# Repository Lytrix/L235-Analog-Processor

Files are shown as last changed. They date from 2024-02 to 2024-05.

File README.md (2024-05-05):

# L-235 Analog Processor ##

### Introduction ###
I was interested in the [SR-235](https://www.thinksrs.com/images/instr/boxcar/SR235_FPlg.jpg) as being the equivalent mathematical processor but then in Analog form which I saw in action on Hainbach's channel using this test equipment here: https://www.youtube.com/watch?v=PS_cn9-rgEs 
Also coming from a digital synthesis world using a Kurzweil K2000R Synthesizer years ago which has an awesome VAST engine with mathematical functions called FUN to combine 2 signals and apply mathematical functions on it, I still was searching for an equivalent module in eurorack but did not find any yet.

So I decided to give it a go and build a eurorack DIY version of this module to have these interesting functions available for waveform manipulation in eurorack.

I found the schematics of the SR-235 with courtesy of Stanford Research Systems:
https://www.thinksrs.com/downloads/pdfs/manuals/Boxcarm.pdf

### Main principe ###

The analog processor uses a 4 deck rotary switch to change the algorith and function. This creates different inputs paths to each IC or opamp circuitry to change the way the voltages are handled. One of the IC's is a precision multipier, the AD534. It can be bought second hand for 10 euros, but newer versions go for a whopping 200 euros. Luckily there is a cheaper version available as SMD version (AD633) which is also 10 euros. By adding an extra opamp to the Z input, you basically have the same circuit. 
The A and B inputs are full wave rectified. This is a falstad testing the out the first circuit path: [Full wave rectification test setup](https://tinyurl.com/27wkvqkx)

### Added functionalities ###

#### 1. Attenuverter with -10/+10V Offset 

Attenuverter + Offset with 2x Gain
https://therepaircafe.wordpress.com/2021/04/04/attenuverter-with-gain-and-offset/

https://tinyurl.com/2bdyzzdu
Based on 2 schematics found to build a good setup for input prepping, similar like the awesome [Olivella Modular Signos](https://www.olivellamodular.com/signos.html).

Precision Attenuverter:
https://kassu2000.blogspot.com/2018/04/precision-attenuverter-mixer.html

Added Offset:
https://modwiggler.com/forum/viewtopic.php?t=103687

#### 1b. VCA CV controlled ####
[Moritz Klein Transistor VCA example](https://www.falstad.com/circuit/circuitjs.html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)

[electronic druid LM13700 example](https://electricdruid.net/wp-content/uploads/2020/04/EurorackVintageVCA-scaled.jpg)

[DIY VCA with transistors](https://sound-au.com/project213.htm)

Nice payed version: https://modulargrid.net/e/teia-mapvolt

AD633 example
https://modulargrid.net/e/seismic-industries-polarizer

LM13700 example
https://www.haraldswerk.de/VCA/Quad_VCA/Quad_VCA.html

AS3363 example

#### 2. Continuous Argument Filter X with reduced range ####
I reached out to Hainbach who was willing to share some photographs on the internals so I could look for the same brand of components.
I also incorporated his suggestion of changing the filter to a continous potentiometer and limit it to the first 3 steps (0-1M Ohms) to keep it in the audible range.

#### 3. Normalized Patch points before and after each circuit #### 
I wanted to include as many patch points as possible to have a plethora of normalised extra in/outputs on each of the different circuit blocks which are already in the SR-235. Thaty way it can be used as an ARP2600/MS-20 type of pre-routed unit and be able to use a single part of the chain if needed.

#### 4. Bi Polar Half Wave rectification ####
Beside the existing circuits already in the module like full wave rectification, a bi polar half wave option to switch to is also added.
I took inspiration of these nice utility modules where for example the CFM can be utilised to add to separate positive and negative half waves to create new waveshapes easily:
- [Mutable Kinks](https://pichenettes.github.io/mutable-instruments-documentation/modules/kinks/) Signal prep: Invert/Half Wave/Full Wave
- [BiPolar Half Wave Rectifier](http://www.cfmodular.com/BHWR)

To be able to combine new rectified waveshapes I decided to add switches for inversion and positive/negative half wave rectification so the main signal chain can easily be changed.

#### 5. CV control over the selected Argument and Function
A eurorack conversion wouldn't be complete with complete CV control over everything. Therefore I've added CV control to select different circuits via a multiplexer and using a 3-bit Flash ADC to have proper audio rate speed (hopefully!)
- [3-bit Flash ADC test](https://tinyurl.com/2b6dmdgn)

#### 6. CV control over the Argument Filter ####
The Argument Filter is upgraded to a full integrator as was used on the System 700 of Roland.
http://yusynth.net/gear/ROLAND/R700-schematics/707-INSTR-INTERF.pdf

To control the filter a Variable Resistor Ciruit is needed to change the resistance from 0-500k using a BF245 or J112:
https://www.edn.com/a-guide-to-using-fets-for-voltage-controlled-circuits-part-1
and
https://www.ednasia.com/A-guide-to-using-FETs-for-voltage-controlled-circuits--Part-2/ 

https://i.stack.imgur.com/XX1wH.png

#### 7. Additional processing types with AD633 ####

https://www.eddybergman.com/2023/06/AD633ringmodulator.html

http://seismic.industries/wp-content/uploads/2017/08/DIY_Workshop_POLARIZER_Documentation.pdf

1. Frequency Doubler (=Voltage Squarer) (Normalize output A to B to accompish this)
2. Waveshaper (=Voltage Divider A/10*B) W output to negative input opamp to Y1. Output opamp is output. 
4. Square rooter
5. Phase angle detector
6. Rectifier (already have circuits for)
7. VCA 
8. Variable Resistor
10. Ring/AM Modulator (=Multiplier) ([example1](https://musicfromouterspace.com/analogsynth_new/THE_CAVE/Ring%20Mod%20Old%20Design%20I/RingModulator.htm), [example2](https://musicfromouterspace.com/index.php?MAINTAB=SYNTHDIY&VPW=1352&VPH=697))

Great single unit with attenuators:
http://macumbista.net/?p=1314

More in depth:
https://web.archive.org/web/20070123153159/http://www.sowa.synth.net/modular/rm.html
with [schematic](https://web.archive.org/web/20070121113438/http://www.sowa.synth.net/modular/m_rm.gif)
And this example has some GREAT audio examples! Especially the divide creates really nice distortion!:
http://m.bareille.free.fr/modular1/warp633/warp633.htm

And another RM example
https://gitlab.com/rsholmes/ringer

Nice 3hp example:
https://recklessexperimentationaudio.com/products/algebra-lite

Frequency Doubling : Can be done with Waveshaper + gain.

Wavefolder/Ring Mod example:
https://note.com/solder_state/n/n9d138d74b39d

AD633 examples
https://www.youtube.com/watch?v=m6MqNZ7H99w

### Schematic overview of functions with in/outputs ###
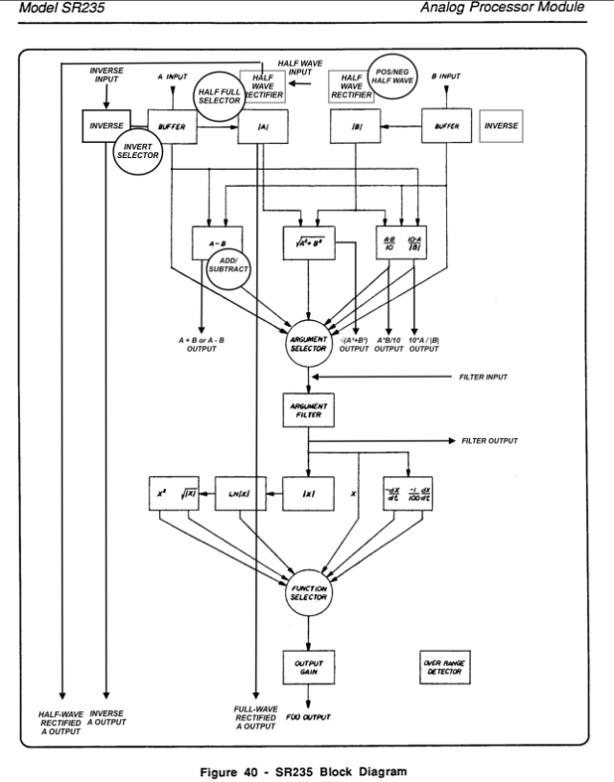
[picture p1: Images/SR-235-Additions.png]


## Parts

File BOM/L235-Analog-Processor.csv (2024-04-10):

Reference | Value | Footprint | Qty
C1, C2, C5, C6 | 100pF | Capacitor_SMD:C_0402_1005Metric | 4
C3 | 0.0033uF Mylar | Capacitor_THT:C_Rect_L7.0mm_W2.5mm_P5.00mm | 1
C4, C11-C24, C26-C37, C40-C60, C62-C82 | 100nF | Capacitor_SMD:C_0402_1005Metric | 69
C7 | 0.1uF | Capacitor_THT:C_Rect_L7.0mm_W2.5mm_P5.00mm | 1
C8 | 100pf | Capacitor_SMD:C_0402_1005Metric | 1
C9 | 1nF | Capacitor_SMD:C_0402_1005Metric | 1
C10 | 10nF | Capacitor_SMD:C_0402_1005Metric | 1
C25 | 22pF | Capacitor_SMD:C_0402_1005Metric | 1
C38, C39 | 10uF | Capacitor_THT:C_Radial_D5.0mm_H7.0mm_P2.00mm | 2
C61 | 330nF | Capacitor_SMD:C_0402_1005Metric | 1
D1 | U19,1 | Diode_SMD:D_0402_1005Metric | 1
D2 | U19,2 | Diode_SMD:D_0402_1005Metric | 1
D3, D30, D32 | U19,3 | Diode_SMD:D_0402_1005Metric | 3
D4, D29, D31 | U19,4 | Diode_SMD:D_0402_1005Metric | 3
D5 | U19,5 | Diode_SMD:D_0402_1005Metric | 1
D6 | U19,6 | Diode_SMD:D_0402_1005Metric | 1
D7 | U19,7 | Diode_SMD:D_0402_1005Metric | 1
D8 | U19,8 | Diode_SMD:D_0402_1005Metric | 1
D9 | U20,6 | Diode_SMD:D_0402_1005Metric | 1
D10 | U20,7 | Diode_SMD:D_0402_1005Metric | 1
D11 | U21,1 | Diode_SMD:D_0402_1005Metric | 1
D12 | U21,2 | Diode_SMD:D_0402_1005Metric | 1
D13 | U21,3 | Diode_SMD:D_0402_1005Metric | 1
D14 | U21,4 | Diode_SMD:D_0402_1005Metric | 1
D15 | U21,5 | Diode_SMD:D_0402_1005Metric | 1
D16 | U21,8 | Diode_SMD:D_0402_1005Metric | 1
D17 | U21,7 | Diode_SMD:D_0402_1005Metric | 1
D18 | U21,6 | Diode_SMD:D_0402_1005Metric | 1
D19 | U20,8 | Diode_SMD:D_0402_1005Metric | 1
D20 | U20,2 | Diode_SMD:D_0402_1005Metric | 1
D21 | U20,1 | Diode_SMD:D_0402_1005Metric | 1
D22 | ~ | Diode_SMD:D_0402_1005Metric | 1
D23 | U20,3 | Diode_SMD:D_0402_1005Metric | 1
D24 | LED | LED_THT:LED_D3.0mm_Clear | 1
D25 | U20,4 | Diode_SMD:D_0402_1005Metric | 1
D26 | U20,5 | Diode_SMD:D_0402_1005Metric | 1
D27, D28 | 1N5819 | Diode_SMD:D_0402_1005Metric | 2
H1-H3 | MountingHole | MountingHole:MountingHole_3.2mm_M3_DIN965 | 3
IC2 | AD633ARZ-RL | Package_SO:SOIC-8_3.9x4.9mm_P1.27mm | 1
J1 | Input A | Custom_Footprints:Cliff_3.5mm_Stereo_Jack | 1
J2 | Input B | Custom_Footprints:Cliff_3.5mm_Stereo_Jack | 1
J3 | Function IN | Custom_Footprints:Cliff_3.5mm_Stereo_Jack | 1
J4 | ( 10A / |B| ) / ( A * B / 10 ) | Custom_Footprints:Cliff_3.5mm_Stereo_Jack | 1
J5 | Output F(x) | Custom_Footprints:Cliff_3.5mm_Stereo_Jack | 1
J6 | Power | Custom_Footprints:Eurorack_10_pin_header | 1
J7 | Full-Wave Rectifier B | Custom_Footprints:Cliff_3.5mm_Stereo_Jack | 1
J8 | A - B | Custom_Footprints:Cliff_3.5mm_Stereo_Jack | 1
J9 | Negative Half-Wave Rectifier B | Custom_Footprints:Cliff_3.5mm_Stereo_Jack | 1
J10 | Half Wave A + -B | Custom_Footprints:Cliff_3.5mm_Stereo_Jack | 1
J11 | Inverted Out B | Custom_Footprints:Cliff_3.5mm_Stereo_Jack | 1
J12, J13 | CV Select | Custom_Footprints:Cliff_3.5mm_Stereo_Jack | 2
J14 | Conn_01x12_Pin | Connector_PinHeader_2.54mm:PinHeader_1x18_P2.54mm_Vertical | 1
J15 | Inverted Out A | Custom_Footprints:Cliff_3.5mm_Stereo_Jack | 1
J16 | Full-Wave Rectifier A | Custom_Footprints:Cliff_3.5mm_Stereo_Jack | 1
J17 | Half-Wave Rectifier A | Custom_Footprints:Cliff_3.5mm_Stereo_Jack | 1
J18 | Custom_Footprints:Cliff_3.5mm_Stereo_Jack | 1
J19 | Conn_01x12_Socket | Connector_PinHeader_2.54mm:PinHeader_1x18_P2.54mm_Vertical | 1
R1, R3-R14, R19, R20, R22, R23, R26, R29, R31, R32, R34, R36, R39-R42, R44, R50, R53, R66-R69, R72, R75, R84-R86, R100, R102, R103, R111 | 10k | Resistor_SMD:R_0402_1005Metric | 43
R2, R17, R60-R62, R80, R83, R90, R94-R97, R105-R109, R113 | 1k | Resistor_SMD:R_0402_1005Metric | 18
R15, R27, R58, R59, R77, R78, R99, R112 | 100k | Resistor_SMD:R_0402_1005Metric | 8
R16, R64, R98 | 3k | Resistor_SMD:R_0402_1005Metric | 3
R18 | 300k | Resistor_SMD:R_0402_1005Metric | 1
R21, R33 | 75k | Resistor_SMD:R_0402_1005Metric | 2
R24, R28, R30 | 20k | Resistor_SMD:R_0402_1005Metric | 3
R25 | 7.1k | Resistor_SMD:R_0402_1005Metric | 1
R35, R37, R38, R82, R87-R89, R91-R93 | 180 | Resistor_SMD:R_0402_1005Metric | 10
R43, R54 | 47k | Resistor_SMD:R_0402_1005Metric | 2
R45, R52 | 470k | Resistor_SMD:R_0402_1005Metric | 2
R46 | 200 | Resistor_SMD:R_0402_1005Metric | 1
R47, R48 | 100 | Resistor_SMD:R_0402_1005Metric | 2
R49 | 10k thermistor | Resistor_SMD:R_0402_1005Metric | 1
R51 | 330k | Resistor_SMD:R_0402_1005Metric | 1
R57 | 10M | Resistor_SMD:R_0402_1005Metric | 1
R63 | 4.3k | Resistor_SMD:R_0402_1005Metric | 1
R65, R110 | 2k | Resistor_SMD:R_0402_1005Metric | 2
R70, R74 | 11k | Resistor_SMD:R_0402_1005Metric | 2
R71, R73 | 12k | Resistor_SMD:R_0402_1005Metric | 2
R76, R79 | 1.0M | Resistor_SMD:R_0402_1005Metric | 2
R81 | 220 | Resistor_SMD:R_0402_1005Metric | 1
R101 | 18k | Resistor_SMD:R_0402_1005Metric | 1
R104 | 4.7k | Resistor_SMD:R_0402_1005Metric | 1
RV1-RV3 | 50k | Potentiometer_THT:Potentiometer_Bourns_3339H_Vertical | 3
RV4, RV6 | 500k | Potentiometer_THT:Potentiometer_Bourns_3339H_Vertical | 2
RV5 | 100k | Potentiometer_THT:Potentiometer_Bourns_3339H_Vertical | 1
RV7 | 500k | Potentiometer_THT:Potentiometer_Alpha_RD901F-40-00D_Single_Vertical | 1
RV8-RV10 | 100k | Potentiometer_THT:Potentiometer_Alpha_RD901F-40-00D_Single_Vertical | 3
RV11, RV12 | 50k | Potentiometer_THT:Potentiometer_Alpha_RD901F-40-00D_Single_Vertical | 2
TR1-TR5 | FMBM5551 | Package_TO_SOT_SMD:SOT-23-6_Handsoldering | 5
U1-U12, U37 | TL082 | Package_SO:SOIC-8_3.9x4.9mm_P1.27mm | 13
U13 | TL084 | Package_SO:SOIC-14_3.9x8.7mm_P1.27mm | 1
U14 | RC4580 | Package_SO:SOIC-8_3.9x4.9mm_P1.27mm | 1
U15, U17 | TL082 | Package_SO:SO-8_3.9x4.9mm_P1.27mm | 2
U18 | LM4040DBZ-10 | Package_TO_SOT_SMD:SOT-23 | 1
U19, U31 | 74HC148 | Package_SO:SOIC-16W_5.3x10.2mm_P1.27mm | 2
U20, U21, U29, U30 | LM339 | Package_SO:SOIC-14_3.9x8.7mm_P1.27mm | 4
U22-U26, U28, U32-U35 | DG4051E | Package_SO:TSSOP-16-1EP_4.4x5mm_P0.65mm_EP3x3mm | 10
U27 | 74LS151 | Package_SO:TSSOP-16-1EP_4.4x5mm_P0.65mm_EP3x3mm | 1
U36 | LM78M05_TO252 | Package_TO_SOT_SMD:TO-252-2 | 1

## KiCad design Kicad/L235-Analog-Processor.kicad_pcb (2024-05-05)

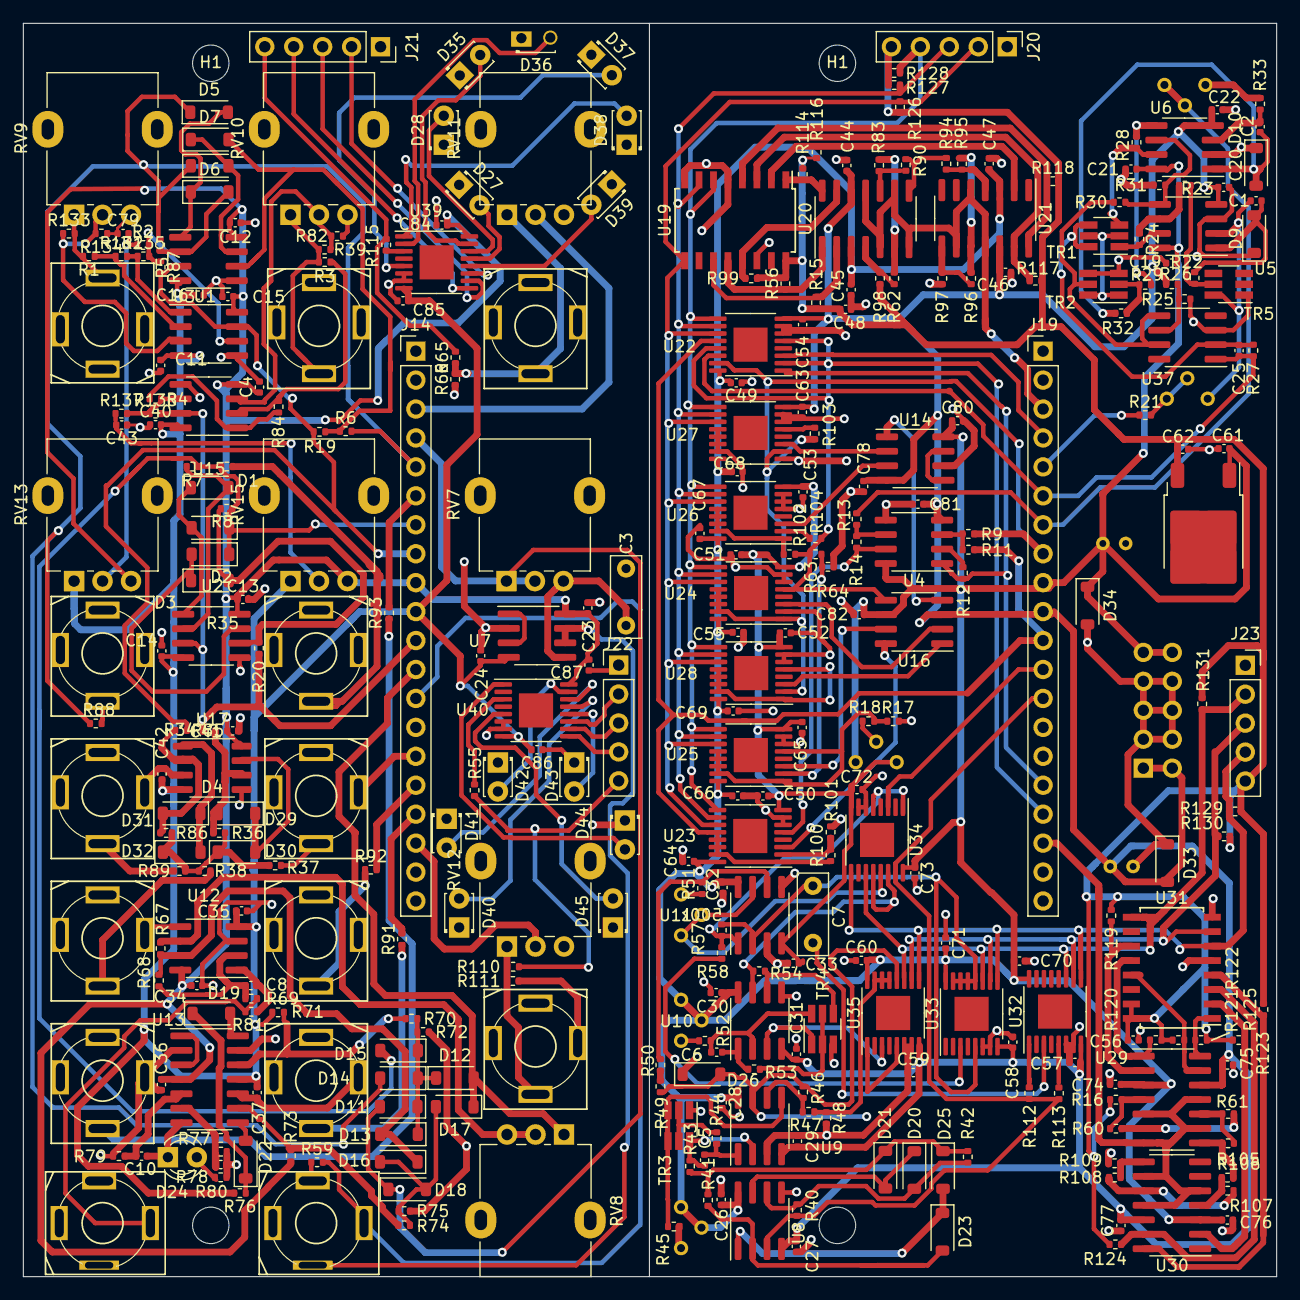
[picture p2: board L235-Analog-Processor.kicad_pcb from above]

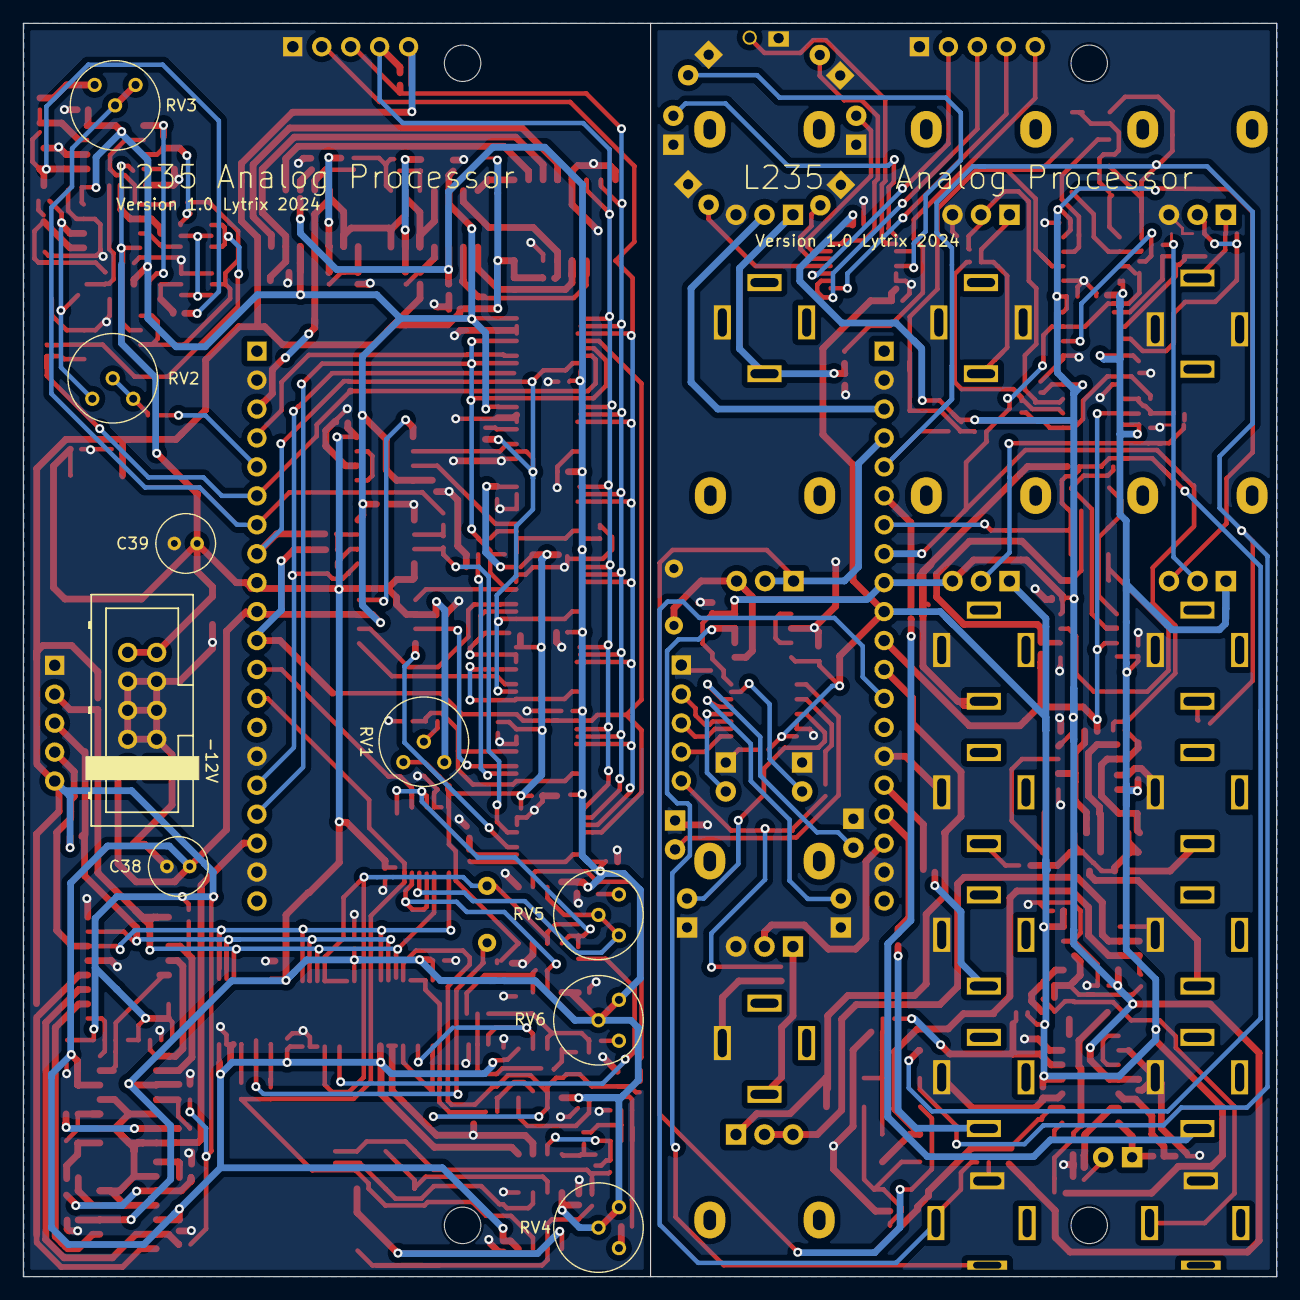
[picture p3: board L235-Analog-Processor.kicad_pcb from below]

Board: 2 copper layers, 110.0 x 110.0 mm, 347 parts (9 on the bottom side), 187 nets.

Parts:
C1, C2, C5, C6: 100pF; C_0402_1005Metric
C3: 0.0033uF Mylar; C_Rect_L7.0mm_W2.5mm_P5.00mm
C4, C11, C12, C13, C14, C15, C16, C19, C20, C21, C22, C23, C24, C26, C27, C28, C29, C30, C31, C32, C33, C34, C35, C36, C37, C40, C41, C42, C43, C44, C45, C46, C47, C48, C49, C50, C51, C52, C53, C54, C55, C56, C57, C58, C59, C60, C62, C63, C64, C65, C66, C67, C68, C69, C70, C71, C72, C73, C74, C75, C76, C77, C78, C79, C80, C81, C82, C84, C85, C86, C87: 100nF; C_0402_1005Metric
C7: 0.1uF; C_Rect_L7.0mm_W2.5mm_P5.00mm
C8: 100pf; C_0402_1005Metric
C9: 1nF; C_0402_1005Metric
C10: 10nF; C_0402_1005Metric
C25: 22pF; C_0402_1005Metric
C38, C39: 10uF; C_Radial_D5.0mm_H7.0mm_P2.00mm
C61: 330nF; C_0402_1005Metric
D1: U19,1; D_SOD-123
D2: U19,2; D_SOD-123
D3, D30, D32: U19,3; D_SOD-123
D4, D29, D31: U19,4; D_SOD-123
D5: U19,5; D_SOD-123
D6: U19,6; D_SOD-123
D7: U19,7; D_SOD-123
D8: U19,8; D_SOD-123
D9: U20,6; D_SOD-123
D10: U20,7; D_SOD-123
D11: U21,1; D_SOD-123
D12: U21,2; D_SOD-123
D13: U21,3; D_SOD-123
D14: U21,4; D_SOD-123
D15: U21,5; D_SOD-123
D16: U21,8; D_SOD-123
D17: U21,7; D_SOD-123
D18: U21,6; D_SOD-123
D19: U20,8; D_SOD-123
D20: U20,2; D_SOD-123
D21: U20,1; D_SOD-123
D22: D_SOD-123
D23: U20,3; D_SOD-123
D24: LED; LED_D3.0mm_Clear
D25: U20,4; D_SOD-123
D26: U20,5; D_SOD-123
D27, D28, D35, D36, D37, D38, D39, D40, D41, D42, D43, D44, D45: LED; LED_D1.8mm_W3.3mm_H2.4mm
D33, D34: 1N5819HW; D_SOD-123
H1, H1#2, H3, H3#2: MountingHole; MountingHole_3.2mm_M3_DIN965
J1: Input A; Cliff_3.5mm_Stereo_Jack
J2: Input B; Cliff_3.5mm_Stereo_Jack
J3: Function IN; Cliff_3.5mm_Stereo_Jack
J4: ( 10A / |B| ) / ( A * B / 10 ); Cliff_3.5mm_Stereo_Jack
J5: Output F(x); Cliff_3.5mm_Stereo_Jack
J6: Power; Eurorack_10_pin_header
J7: Full-Wave Rectifier B; Cliff_3.5mm_Stereo_Jack
J8: A - B; Cliff_3.5mm_Stereo_Jack
J9: Negative Half-Wave Rectifier B; Cliff_3.5mm_Stereo_Jack
J10: Half Wave A + -B; Cliff_3.5mm_Stereo_Jack
J12, J13: CV Select; Cliff_3.5mm_Stereo_Jack
J14: Conn_01x20_Pin; PinHeader_1x20_P2.54mm_Vertical
J16: Full-Wave Rectifier A; Cliff_3.5mm_Stereo_Jack
J17: Half-Wave Rectifier A; Cliff_3.5mm_Stereo_Jack
J18: √(A²+B²); Cliff_3.5mm_Stereo_Jack
J19: Conn_01x20_Socket; PinHeader_1x20_P2.54mm_Vertical
J20, J22: Conn_01x05_Socket; PinHeader_1x05_P2.54mm_Vertical
J21, J23: Conn_01x05_Pin; PinSocket_1x05_P2.54mm_Vertical
R1, R2, R3, R27, R58, R59, R77, R78, R84, R87, R112, R132, R137, R138: 100k; R_0402_1005Metric
R4, R39, R43, R54, R82, R133, R134, R135: 47k; R_0402_1005Metric
R5, R6, R7, R8, R9, R11, R12, R13, R14, R19, R20, R22, R23, R26, R29, R31, R32, R34, R36, R40, R41, R42, R44, R50, R53, R66, R67, R68, R69, R72, R75, R85, R86, R100, R102, R103, R111: 10k; R_0402_1005Metric
R15, R56, R99, R114, R116, R117, R118, R119, R120, R121, R122, R123, R124, R125, R126, R127, R128, R129, R130, R131: 4k7; R_0402_1005Metric
R16, R64, R98: 3k; R_0402_1005Metric
R17, R35, R37, R38, R55, R60, R61, R62, R80, R83, R88, R89, R90, R91, R92, R93, R94, R95, R96, R97, R105, R106, R107, R108, R109, R113, R115: 1k; R_0402_1005Metric
R18: 220k; R_0402_1005Metric
R21, R33: 75k; R_0402_1005Metric
R24, R28, R30: 20k; R_0402_1005Metric
R25: 7.1k; R_0402_1005Metric
R45, R52: 470k; R_0402_1005Metric
R46: 200; R_0402_1005Metric
R47, R48: 100; R_0402_1005Metric
R49: 10k thermistor; R_0402_1005Metric
R51: 330k; R_0402_1005Metric
R57: 10M; R_0402_1005Metric
R63: 4.3k; R_0402_1005Metric
R65, R110: 2k; R_0402_1005Metric
R70, R74: 11k; R_0402_1005Metric
R71, R73: 12k; R_0402_1005Metric
R76, R79: 1.0M; R_0402_1005Metric
R81: 220; R_0402_1005Metric
R101: 18k; R_0402_1005Metric
R104: 4.7k; R_0402_1005Metric
RV1, RV5: 100k; Potentiometer_Bourns_3339H_Vertical
RV2, RV3: 50k; Potentiometer_Bourns_3339H_Vertical
RV4, RV6: 500k; Potentiometer_Bourns_3339H_Vertical
RV7: 1M Log; Potentiometer_Alpha_RD901F-40-00D_Single_Vertical
RV8, RV9, RV10, RV13, RV15: 100k; Potentiometer_Alpha_RD901F-40-00D_Single_Vertical
RV11, RV12: 50k; Potentiometer_Alpha_RD901F-40-00D_Single_Vertical
TR1, TR2, TR3, TR4, TR5: FMBM5551; SOT-23-6_Handsoldering
U1, U2, U3, U4, U5, U6, U7, U8, U9, U10, U11, U12, U15, U37: TL082; SOIC-8_3.9x4.9mm_P1.27mm
U13: TL084; SOIC-14_3.9x8.7mm_P1.27mm
U14: RC4580; SOIC-8_3.9x4.9mm_P1.27mm
U16: AD633ARZ-RL; SOIC-8_3.9x4.9mm_P1.27mm
U17: TL082; SO-8_3.9x4.9mm_P1.27mm
U19, U31: 74HC148; SOIC-16W_5.3x10.2mm_P1.27mm
U20, U21, U29, U30: LM339; SOIC-14_3.9x8.7mm_P1.27mm
U22, U23, U24, U25, U26, U27, U28, U32, U33, U34, U35: DG408; TSSOP-16-1EP_4.4x5mm_P0.65mm_EP3x3mm
U36: LM78M05_TO252; TO-252-2
U39, U40: CD4051; TSSOP-16-1EP_4.4x5mm_P0.65mm_EP3x3mm

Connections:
(-dX/dt) or (-dX/dt*1/100): R57.1, R58.2, U11.1, U34.1 (X4), U34.5 (X5)
+5V: C48.2, C56.2, C62.2, J20.5, J21.5, J22.5, J23.5, R15.2, R16.2, R55.1, R56.2, R65.2, R98.2, R99.2, R110.2, R114.2, R115.1, R116.2, R117.2, R118.2, R119.2, R120.2, R121.2, R122.2, R123.2, R124.2, R125.2, R126.2, R127.2, R128.2, R129.2, R130.2, R131.2, U19.16 (VCC), U31.15 (E0), U31.16 (VCC), U36.3 (VO)
+12V: C4.1, C12.1, C13.1, C15.1, C19.1, C21.1, C23.1, C26.1, C28.1, C30.1, C32.1, C34.1, C36.1, C39.1, C41.1, C45.1, C47.1, C49.2, C52.2, C60.2, C61.1, C64.2, C66.2, C67.2, C68.2, C69.2, C70.2, C71.2, C73.2, C74.1, C76.1, C80.1, C82.2, C84.2, C87.2, D34.1 (K), J6.9, J6.10, J14.9, J19.9, R73.1, RV1.1, RV4.1, RV4.2, RV6.1, RV6.2, RV13.3, RV15.3, U1.8 (V+), U2.8 (V+), U3.8 (V+), U4.8 (V+), U5.8 (V+), U6.8 (V+), U7.8 (V+), U8.8 (V+), U9.8 (V+), U10.8 (V+), U11.8 (V+), U12.8 (V+), U13.4 (V+), U14.8 (V+), U15.4 (V-), U16.6 (+VS), U17.8 (V+), U20.3 (V+), U21.3 (V+), U22.16 (VDD), U23.16 (VDD), U24.16 (VDD), U25.16 (VDD), U26.16 (VDD), U27.16 (VDD), U28.16 (VDD), U29.3 (V+), U30.3 (V+), U32.16 (VDD), U33.16 (VDD), U34.16 (VDD), U35.16 (VDD), U36.1 (VI), U39.16 (VDD), U40.16 (VDD)
-12V: C11.2, C14.2, C16.2, C20.2, C22.2, C24.2, C27.2, C29.2, C31.2, C33.2, C35.2, C37.2, C38.2, C40.2, C42.2, C44.2, C46.2, C50.2, C51.2, C53.2, C54.2, C55.2, C57.2, C58.2, C59.2, C63.2, C65.2, C72.2, C75.2, C77.2, C78.2, C81.2, C85.2, C86.2, D33.2 (A), J6.1, J6.2, J14.10, J19.10, R26.1, R71.2, R76.2, RV1.3, RV13.1, RV15.1, U1.4 (V-), U2.4 (V-), U3.4 (V-), U4.4 (V-), U5.4 (V-), U6.4 (V-), U7.4 (V-), U8.4 (V-), U9.4 (V-), U10.4 (V-), U11.4 (V-), U12.4 (V-), U13.11 (V-), U14.4 (V-), U15.8 (V+), U16.3 (-VS), U17.4 (V-), U20.12 (V-), U21.12 (V-), U22.8 (VSS), U23.8 (VSS), U24.8 (VSS), U25.8 (VSS), U26.8 (VSS), U27.8 (VSS), U28.8 (VSS), U29.12 (V-), U30.12 (V-), U32.8 (VSS), U33.8 (VSS), U34.8 (VSS), U35.8 (VSS), U39.8 (VSS), U40.8 (VSS)
-Output: D13.2 (A), D16.1 (K), R67.1, R68.2, U12.7
-|B|: R14.2, U4.7, U23.5 (X5)
<X>: J3.T, J14.13, J19.13, R40.1, R59.2, R112.1, R113.1, U8.3 (+), U34.15 (X2)
A: J14.8, J19.8, R9.1, R19.1, R85.1, R87.2, R103.1, U1.7, U3.3 (+), U22.15 (X2), U24.1 (X4), U24.12 (X3), U24.13 (X0), U24.14 (X1), U24.15 (X2), U27.2 (X6), U28.2 (X6)
A0: J20.2, J21.2, R126.1, U19.9 (A0), U22.11 (A), U23.11 (A), U24.11 (A), U25.11 (A), U26.11 (A), U27.11 (A), U28.11 (A), U39.11 (A)
A1: J20.3, J21.3, R127.1, U19.7 (A1), U22.10 (B), U23.10 (B), U24.10 (B), U25.10 (B), U26.10 (B), U27.10 (B), U28.10 (B), U39.10 (B)
A2: J20.4, J21.4, R128.1, U19.6 (A2), U22.9 (C), U23.9 (C), U24.9 (C), U25.9 (C), U26.9 (C), U27.9 (C), U28.9 (C), U39.9 (C)
A - B: J14.16, J19.16, R12.2, R92.2, U4.1, U22.1 (X4)
AD534_OUT: J14.17, J19.17, R63.2, R91.2, R102.1, R104.1, U16.5 (W), U22.2 (X6), U22.5 (X5), U22.13 (X0), U24.5 (X5)
AD534_X1: U16.7 (X1), U25.3 (X)
AD534_X2: U16.8 (X2), U23.3 (X)
AD534_Y1: U16.1 (Y1), U28.3 (X)
AD534_Y2: U16.2 (Y2), U24.3 (X)
AD534_Z1: U14.3 (+), U26.3 (X)
AD534_Z2: U14.2 (-), U27.3 (X)
B: J14.11, J19.11, R11.1, R20.1, R34.1, R100.1, R138.2, U2.3 (+), U15.7, U22.12 (X3), U23.1 (X4), U23.12 (X3), U23.13 (X0), U23.14 (X1), U23.15 (X2)
B0: J22.2, J23.2, R131.1, U31.9 (A0), U32.11 (A), U33.11 (A), U34.11 (A), U35.11 (A), U40.11 (A)
B1: J22.3, J23.3, R130.1, U31.7 (A1), U32.10 (B), U33.10 (B), U34.10 (B), U35.10 (B), U40.10 (B)
B2: J22.4, J23.4, R129.1, U31.6 (A2), U32.9 (C), U33.9 (C), U34.9 (C), U35.9 (C), U40.9 (C)
B|: D30.1 (K), D32.1 (K), R36.2, R37.1, R38.1, R86.2, R89.1
CA3046_B3: TR4.1, U10.3 (+), U35.3 (X)
CV_FUNCTION: J14.18, J19.18, RV12.2, U29.5 (+), U29.7 (+), U29.9 (+), U29.11 (+), U30.5 (+), U30.9 (+), U30.11 (+)
CV_SELECT: J14.3, J19.3, RV11.2, U20.5 (+), U20.7 (+), U20.9 (+), U20.11 (+), U21.5 (+), U21.9 (+), U21.11 (+)
F1: C7.2, R57.2, U11.2 (-), U33.5 (X5), U33.12 (X3), U33.13 (X0), U33.14 (X1), U33.15 (X2)
F1-1/100: C7.1, U32.3 (X)
F2: R58.1, U33.3 (X)
Function Out: D12.2 (A), D17.1 (K), J14.12, J19.12, RV8.1, U34.3 (X)
GND: C3.2, C4.2, C9.2, C11.1, C12.2, C13.2, C14.1, C15.2, C16.1, C19.2, C20.1, C21.2, C22.1, C23.2, C24.1, C26.2, C27.1, C28.2, C29.1, C30.2, C31.1, C32.2, C33.1, C34.2, C35.1, C36.2, C37.1, C38.1, C39.2, C40.1, C41.2, C42.1, C43.1, C44.1, C45.2, C46.1, C47.2, C48.1, C49.1, C50.1, C51.1, C52.1, C53.1, C54.1, C55.1, C56.1, C57.1, C58.1, C59.1, C60.1, C61.2, C62.1, C63.1, C64.1, C65.1, C66.1, C67.1, C68.1, C69.1, C70.1, C71.1, C72.1, C73.1, C74.2, C75.1, C76.2, C77.1, C78.1, C79.1, C80.2, C81.1, C82.1, C84.1, C85.1, C86.1, C87.1, D9.1 (K), D10.1 (K), D26.1 (K), D27.1 (K), D28.1 (K), D33.1 (K), D34.2 (A), D35.1 (K), D36.1 (K), D37.1 (K), D38.1 (K), D39.1 (K), D40.1 (K), D41.1 (K), D42.1 (K), D43.1 (K), D44.1 (K), D45.1 (K), J1.G, J1.TN, J2.G, J2.TN, J3.G, J4.G, J5.G, J6.3, J6.4, J6.5, J6.6, J6.7, J6.8, J7.G, J8.G, J9.G, J10.G, J12.G, J13.G, J14.2, J14.15, J14.19, J16.G, J17.G, J18.G, J19.2, J19.15, J19.19, J20.1, J21.1, J22.1, J23.1, R17.1, R25.2, R31.1, R48.2, R59.1, R64.1, R66.1, R72.1, R75.1, R78.2, R79.2, R80.1, R82.1, R97.1, R101.2, R109.1, R111.1, R134.1, RV9.3, RV10.3, RV11.3, RV12.3, TR2.3, TR2.4, TR3.1, TR4.3, TR5.1, U1.5 (+), U2.5 (+), U3.5 (+), U4.5 (+), U5.3 (+), U6.2 (-), U7.2 (-), U8.5 (+), U9.3 (+), U10.5 (+), U11.3 (+), U11.5 (+), U12.3 (+), U12.5 (+), U13.2 (-), U13.10 (+), U13.13 (-), U14.6 (-), U15.5 (+), U17.3 (+), U17.5 (+), U19.5 (EI), U19.8 (GND), U19.14 (GS), U22.6 (Inh), U22.7 (VEE), U23.6 (Inh), U23.7 (VEE), U24.2 (X6), U24.6 (Inh), U24.7 (VEE), U25.6 (Inh), U25.7 (VEE), U26.5 (X5), U26.6 (Inh), U26.7 (VEE), U27.1 (X4), U27.6 (Inh), U27.7 (VEE), U27.12 (X3), U27.13 (X0), U27.14 (X1), U27.15 (X2), U28.6 (Inh), U28.7 (VEE), U31.5 (EI), U31.8 (GND), U32.6 (Inh), U32.7 (VEE), U33.6 (Inh), U33.7 (VEE), U34.6 (Inh), U34.7 (VEE), U35.6 (Inh), U35.7 (VEE), U36.2 (GND), U37.3 (+), U39.6 (Inh), U39.7 (VEE), U40.6 (Inh), U40.7 (VEE)
LED_A1: D27.2 (A), U39.13 (X0)
LED_A2: D28.2 (A), U39.14 (X1)
LED_A3: D35.2 (A), U39.15 (X2)
LED_A4: D39.2 (A), U39.12 (X3)
LED_A5: D38.2 (A), U39.1 (X4)
LED_A6: D37.2 (A), U39.5 (X5)
LED_A7: D36.2 (A), U39.2 (X6)
LED_B1: D40.2 (A), U40.13 (X0)
LED_B2: D41.2 (A), U40.14 (X1)
LED_B3: D42.2 (A), U40.15 (X2)
LED_B4: D43.2 (A), U40.12 (X3)
LED_B5: D44.2 (A), U40.1 (X4)
LED_B6: D45.2 (A), U40.5 (X5)
unnamed: C5.2, R44.1, U9.1
unnamed: C6.2, R53.1, U10.1
unnamed: C8.2, R81.2, U12.1
unnamed: C43.2, R137.1, RV15.2
unnamed: C79.2, R2.1, RV13.2
unnamed: D1.2 (A), R7.1, U2.2 (-)
unnamed: D1.1 (K), D2.2 (A), U2.1
unnamed: D3.2 (A), D4.1 (K), U2.7
unnamed: D4.2 (A), R8.1, R20.2, U2.6 (-)
unnamed: D5.2 (A), D6.1 (K), U3.1
unnamed: D6.2 (A), R5.1, U3.2 (-)
unnamed: D7.2 (A), R6.1, R19.2, U3.6 (-)
unnamed: D7.1 (K), D8.2 (A), U3.7
unnamed: C1.2, D9.2 (A), R22.1, U5.1
unnamed: C2.1, D10.2 (A), R32.1, U6.1
unnamed: D11.1 (K), D12.1 (K), D13.1 (K), D14.1 (K), D15.1 (K), R70.2, R72.2
unnamed: D16.2 (A), D17.2 (A), D18.2 (A), R74.2, R75.2
unnamed: D19.2 (A), U13.14
unnamed: D19.1 (K), D22.1 (K), R76.1, R77.2
unnamed: D20.2 (A), R40.2, R42.1, U8.6 (-)
unnamed: D20.1 (K), D21.2 (A), U8.7
unnamed: D21.1 (K), D25.1 (K), R41.2, R42.2, R43.1
unnamed: D22.2 (A), U13.8
unnamed: D23.2 (A), R41.1, U8.2 (-)
unnamed: D23.1 (K), D25.2 (A), U8.1
unnamed: D24.2 (A), R80.2
unnamed: C10.2, D24.1 (K), U13.7
unnamed: D29.2 (A), R34.2, R36.1, U17.6 (-)
unnamed: D29.1 (K), D30.2 (A), U17.7
unnamed: D31.2 (A), R85.2, R86.1, U17.2 (-)
unnamed: D31.1 (K), D32.2 (A), U17.1
unnamed: J1.T, R1.2, R133.2, RV9.1
unnamed: J2.T, R3.1, R39.2, RV10.1
unnamed: J4.T, R91.1
unnamed: J5.T, R69.1, R81.1
unnamed: J7.T, R35.2
unnamed: J8.T, R92.1
unnamed: J9.T, R37.2
unnamed: J10.T, R38.2
unnamed: J12.T, R65.1, R66.2, RV11.1
unnamed: J13.T, R110.1, R111.2, RV12.1
unnamed: J16.T, R88.2
unnamed: J17.T, R89.2
unnamed: J18.T, R93.1
unnamed: R4.1, R84.2, U15.1
unnamed: R18.2, RV1.2
unnamed: R21.2, RV2.1, RV2.2
unnamed: R22.2, R23.1, TR5.5
unnamed: R24.2, TR1.1, U5.7
unnamed: R28.1, TR1.3, U6.7
unnamed: R29.2, R32.2, TR2.2
unnamed: R33.2, RV3.1
unnamed: R44.2, TR3.2, TR3.5
unnamed: R45.2, RV4.3
unnamed: R49.1, R50.2
unnamed: R51.1, RV5.1
unnamed: R52.2, RV6.3
unnamed: R53.2, TR4.2, TR4.5
unnamed: R132.2, R135.1, U1.1
unnamed: TR1.2, TR1.5, TR2.1, TR2.6
unnamed: R133.1, R134.2, RV9.2, U1.3 (+)
unnamed: R1.1, R132.1, U1.2 (-)
unnamed: R2.2, R87.1, R135.2, U1.6 (-)
unnamed: R9.2, R11.2, U4.3 (+)
unnamed: R12.1, U4.2 (-)
unnamed: R13.2, R14.1, U4.6 (-)
unnamed: C1.1, RV2.3, TR5.6, U5.2 (-)
unnamed: R30.2, R31.2, U5.5 (+), U6.6 (-)
unnamed: R23.2, R24.1, U5.6 (-)
unnamed: C2.2, R33.1, U6.3 (+)
unnamed: R28.2, R29.1, U6.5 (+)
unnamed: U7.1, U7.3 (+)
unnamed: C3.1, RV7.3, U7.5 (+)
unnamed: J3.TN, U7.6 (-), U7.7
unnamed: C5.1, R43.2, TR3.6, U9.2 (-)
unnamed: R45.1, TR3.3, TR3.4, U9.5 (+)
unnamed: R46.2, R47.1, U9.6 (-)
unnamed: C6.1, R52.1, TR4.6, U10.2 (-)
unnamed: R54.2, TR4.4, U10.6 (-)
unnamed: R50.1, R51.2, U11.6 (-)
unnamed: C8.1, R68.1, R69.2, U12.2 (-)
unnamed: R67.2, RV8.2, RV8.3, U12.6 (-)
unnamed: U13.1, U13.3 (+)
unnamed: C10.1, R79.1, U13.5 (+)
unnamed: C9.1, R77.1, R78.1, U13.6 (-)
unnamed: R73.2, R74.1, U13.9 (-)
unnamed: R70.1, R71.1, U13.12 (+)
unnamed: U14.5 (+), U14.7
unnamed: R39.1, R82.2, RV10.2, U15.3 (+)
unnamed: R3.2, R84.1, U15.2 (-)
unnamed: R4.2, R137.2, R138.1, U15.6 (-)
unnamed: U14.1, U16.4 (Z)
unnamed: R15.1, U19.11 (1), U20.2
unnamed: R56.1, U19.12 (2), U20.1
unnamed: R99.1, U19.13 (3), U20.13
unnamed: R114.1, U19.1 (4), U20.14
unnamed: R116.1, U19.2 (5), U21.2
unnamed: R117.1, U19.3 (6), U21.13
unnamed: R118.1, U19.4 (7), U21.14
unnamed: R62.2, R98.1, U20.4 (-)
unnamed: R62.1, R83.2, U20.6 (-)
unnamed: R83.1, R90.2, U20.10 (-)
unnamed: R90.1, R94.2, U20.8 (-)
unnamed: R94.1, R95.2, U21.4 (-)
unnamed: R95.1, R96.2, U21.10 (-)
unnamed: R96.1, R97.2, U21.8 (-)
unnamed: R100.2, R101.1, U23.2 (X6)
unnamed: R102.2, U26.1 (X4), U26.12 (X3), U26.13 (X0), U26.14 (X1), U26.15 (X2)
unnamed: R104.2, U26.2 (X6)
unnamed: R103.2, U27.5 (X5)
unnamed: R16.1, R60.2, U29.4 (-)
unnamed: R60.1, R61.2, U29.6 (-)
unnamed: R61.1, R105.2, U29.10 (-)
unnamed: R105.1, R106.2, U29.8 (-)
unnamed: R106.1, R107.2, U30.4 (-)
unnamed: R107.1, R108.2, U30.10 (-)
unnamed: R108.1, R109.2, U30.8 (-)
unnamed: R119.1, U29.2, U31.11 (1)
unnamed: R120.1, U29.1, U31.12 (2)
unnamed: R121.1, U29.13, U31.13 (3)
unnamed: R122.1, U29.14, U31.1 (4)
unnamed: R123.1, U30.2, U31.2 (5)
unnamed: R124.1, U30.13, U31.3 (6)
unnamed: R125.1, U30.14, U31.4 (7)
unnamed: R112.2, U32.1 (X4)
unnamed: R113.2, U32.5 (X5)
unnamed: C25.1, R27.1, TR1.4, TR1.6, U37.2 (-)
unnamed: R30.1, TR2.5, U37.5 (+), U37.7
unnamed: R25.1, R26.2, U37.6 (-)
unnamed: R115.2, U39.3 (X)
unnamed: R55.2, U40.3 (X)
Sine: R63.1, R64.2, U25.2 (X6)
Volt_ref_X: R17.2, R18.1, U25.1 (X4), U25.5 (X5), U25.12 (X3), U25.13 (X0), U25.14 (X1), U25.15 (X2)
Volt_ref_Y: U28.1 (X4), U28.5 (X5), U28.12 (X3), U28.13 (X0), U28.14 (X1), U28.15 (X2)
X: D11.2 (A), D18.1 (K), J14.4, J19.4, RV7.1, RV7.2, U22.3 (X)
X²: D26.2 (A), R46.1, R49.2, U9.7, U35.1 (X4), U35.5 (X5), U35.12 (X3)
ln |x|: RV5.2, RV5.3, U11.7, U34.13 (X0)
|A|: D5.1 (K), D8.1 (K), D14.2 (A), J14.5, J19.5, R5.2, R6.2, R21.1, R88.1
|B|: D2.1 (K), D3.1 (K), D15.2 (A), J14.7, J19.7, R7.2, R8.2, R13.1, R35.1, RV3.2, RV3.3
√(A²+B²): C25.2, J14.6, J19.6, R27.2, R93.2, U22.14 (X1), U37.1
√|x|: R47.2, R48.1, U35.13 (X0), U35.14 (X1), U35.15 (X2)
√|x| or X²: R54.1, U10.7, U34.12 (X3), U34.14 (X1)

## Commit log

2024-02-14 Moved Kicad files to kicad folder
    [L235-Analog-Processor.kicad_pcb, L235-Analog-Processor.kicad_sch]
2024-02-14 Fixed symbol pins AD534JH, Added IC power Rectifier/Inverse
    [L235-Analog-Processor.kicad_sch]
2024-02-14 fixed double U14 annotation
    [L235-Analog-Processor.kicad_sch]
2024-02-14 fixed double U16 annotation
    [L235-Analog-Processor.kicad_sch]
2024-04-04 Changed parts to smd and added CV selector
    [L235-Analog-Processor.kicad_pcb, L235-Analog-Processor.kicad_sch]
2024-04-04 Added example of 3-bit flash adc and explained choice AD633
    [L235-Analog-Processor.kicad_pcb]
2024-04-05 Added header and mounting points
    [L235-Analog-Processor.kicad_pcb, L235-Analog-Processor.kicad_sch]
2024-04-10 Optimized PCB routing, started with variable resistor
    [L235-Analog-Processor.csv, L235-Analog-Processor.kicad_pcb, L235-Analog-Processor.kicad_sch]
2024-04-11 All components routed
    [L235-Analog-Processor.kicad_pcb, L235-Analog-Processor.kicad_sch]
2024-04-11 Fixed missing routing voltage/gnd
    [L235-Analog-Processor.kicad_pcb, L235-Analog-Processor.kicad_sch]
2024-04-12 Added Frontpanel
    [L235-Analog-Processor.kicad_pcb]
2024-04-12 changed diode footprints to SOT-123
    [L235-Analog-Processor.kicad_pcb, L235-Analog-Processor.kicad_sch]
2024-04-15 Added test run
    [BOM-L235-Analog-Processor.csv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]
2024-04-17 Added leds selectors
    [L235-Analog-Processor-Frontpanel.kicad_pcb, L235-Analog-Processor.kicad_pcb, L235-Analog-Processor.kicad_sch]
2024-04-17 Fixed frontpanel and moved overload led
    [L235-Analog-Processor-Frontpanel.kicad_pcb]
2024-04-18 Added missing Vlogic to comparators
    [L235-Analog-Processor.kicad_pcb, L235-Analog-Processor.kicad_sch]
2024-04-18 Flipped +- comparators to fix H/L order to actually work with logic table
    [L235-Analog-Processor.kicad_pcb, L235-Analog-Processor.kicad_sch]
2024-04-18 Cleanup trace thickness, text alignment
    [L235-Analog-Processor.kicad_pcb, L235-Analog-Processor.kicad_sch]
2024-04-19 Removed invert jacks for attenuverter + offset knob
    [L235-Analog-Processor.kicad_pcb, L235-Analog-Processor.kicad_sch]
2024-04-23 Replaced 4051 with DG408 to allow negative -10V voltages
    [L235-Analog-Processor.kicad_pcb, L235-Analog-Processor.kicad_sch]
2024-04-23 Updated frontpanel with Bias knobs, removing invert outs
    [L235-Analog-Processor-Frontpanel.kicad_pcb]
2024-05-05 Fixed attenuverter circuit after breadboard testing
    [L235-Analog-Processor-Frontpanel.kicad_pcb, L235-Analog-Processor.kicad_pcb, L235-Analog-Processor.kicad_sch]
